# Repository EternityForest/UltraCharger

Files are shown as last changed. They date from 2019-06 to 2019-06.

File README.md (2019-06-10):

# UltraCharger
Highly experimental I2C solar battery charger frontend 

This little board is smaller than a buisiness card and basically acts as a frontend for ORing two inputs(2.1mm barrel),

putting the power through a buck-boost into a battery, measuring battery voltage and charge current, and providing 3.3v on the STEMMA
connector through a LDO regulator(Efficiency isn't an issue given the very low current needed to wake up one a second and do MPPT, and
occasionally report status).

There's no UI, it's meant for use with an ESP8266 breakout and UI via a remote machine.

This makes a ton of compromises to be smaller than a business card and on 2 layers. It's not tested and won't be till
I get the PCBs back. However it has been designed to be about as safe as any other consumer microcontroller-powered charger, when used
with the appropriate protection PCB for your battery.

The core is a 1A switching regulator set to 21V, for charging Ryobi One+ batteries. Even if the MCU fails it will not reach unsafe voltages.

That also should be witin the safe range of any decent 4S lithium protection PCB, unless they make thise crappier than I think,
so you should be able to charge 12V batteries and various LTO batteries.

You likely won't be getting more than 12-20 watts with this thing, and efficiency isn't fantastic, but it should be robust against all manner or transients and bad connections, aside from reverse battery which it handles with a clamp that trips the fuse or protection circuit you hopefully are using.

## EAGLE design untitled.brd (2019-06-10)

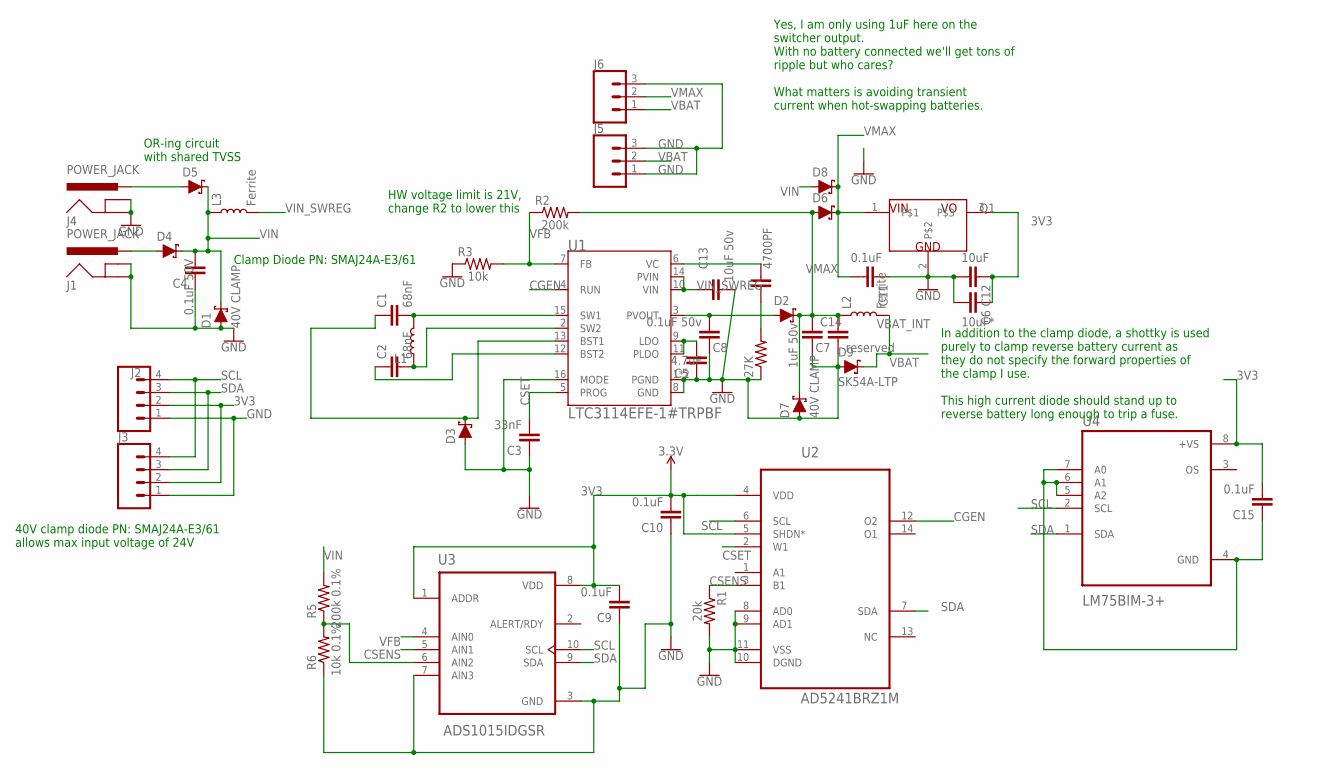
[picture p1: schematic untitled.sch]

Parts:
27K: 0805-EZ
4700PF: 1.0uF; 0805-EZ
C1, C2: 68nF; 0805-EZ
C3: 33nF; 0805-EZ
C4: 0.1uF 50V; 0805-EZ
C5: 4.7uF; 0805-EZ
C6: 10uF*; 0805-EZ
C7: reserved; 1206
C8: 0.1uF 50v; 0805-EZ
C9, C10, C11, C15: 0.1uF; 0805-EZ
C12: 10uF; 0805-EZ
C13: 10uF 50v; 1206
C14: 1uF 50v; 0805-EZ
D1, D7: 40V CLAMP; SMA-DIODE
D2, D3, D4, D5, D6, D8: 3A/40V/500mV; SMA-DIODE
D9: SK54A-LTP; SMA-DIODE
J1, J4: POWER_JACK; POWER_JACK_PTH
J2, J3: CONN_04JST-PTH-VERT; JST-4-PTH-VERT
J5, J6: CONN_03SCREW_LOCK; SCREWTERMINAL-3.5MM-3_LOCK.007S
L1: 27µH/±20%/3.3A; INDUCTOR_SDR1307
L2, L3: Ferrite; 0805
Q1: BD433M5FP-CE2TO252_STM; TO252_STM
R1: 20k; 0805-EZ
R2: 200k; 0805-EZ
R3: 10k; 0805-EZ
R5: 200k 0.1%; 0805-EZ
R6: 10k 0.1%; 0805-EZ
U1: LTC3114EFE-1#TRPBF; SOP65P640X110-17N
U2: AD5241BRZ1M; SOIC127P600X175-14N
U3: ADS1015IDGSR; SOP50P490X110-10N
U4: LM75BIM-3+; SOIC127P600X175-8N

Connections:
3V3: C6.1, C9.2, C10.2, C12.1, C15.2, J2.2, J3.2, Q1.3, U2.4 (VDD), U2.5 (SHDN*), U3.1 (ADDR), U3.8 (VDD), U4.8 (+VS)
CGEN: U1.4 (RUN), U2.12 (O2)
CSENS: R1.1, U2.3 (B1), U3.5 (AIN1)
CSET: C3.2, U1.5 (PROG), U2.2 (W1)
GND: 27K.1, C3.1, C4.1, C5.1, C6.2, C7.1, C8.1, C9.1, C10.1, C11.1, C12.2, C13.2, C14.2, D1.A, D3.A, D7.A, D9.A, J1.GND, J1.GNDBREAK, J2.1, J3.1, J4.GND, J4.GNDBREAK, J5.1, J5.3, J6.3, Q1.2, R1.2, R3.1, R6.1, U1.1 (PGND), U1.8 (GND), U1.16 (MODE), U1.17 (PGND), U2.8 (AD0), U2.9 (AD1), U2.10 (DGND), U2.11 (VSS), U3.3 (GND), U3.7 (AIN3)
unnamed: C1.2, L1.P$2 (2), U1.15 (SW1)
unnamed: C2.2, L1.P$1 (1), U1.2 (SW2)
unnamed: C1.1, D3.C, U1.13 (BST1)
unnamed: C2.1, U1.12 (BST2)
unnamed: D4.A, J1.PWR
unnamed: R5.1, R6.2, U3.6 (AIN2)
unnamed: C15.1, U4.4 (GND), U4.5 (A2), U4.6 (A1), U4.7 (A0)
unnamed: D5.A, J4.PWR
unnamed: C8.2, D2.A, U1.3 (PVOUT)
unnamed: C5.2, U1.9 (LDO), U1.11 (PLDO)
unnamed: 4700PF.2, U1.6 (VC)
unnamed: 27K.2, 4700PF.1
SCL: J2.4, J3.4, U2.6 (SCL), U3.10 (SCL), U4.2 (SCL)
SDA: J2.3, J3.3, U2.7 (SDA), U3.9 (SDA), U4.1 (SDA)
VBAT: D9.C, J5.2, J6.1, L2.2
VBAT_INT: C7.2, C14.1, D2.C, D6.A, D7.C, L2.1, R2.2
VFB: R2.1, R3.2, U1.7 (FB), U3.4 (AIN0)
VIN: C4.2, D1.C, D4.C, D5.C, D8.A, L3.1, R5.2
VIN_SWREG: C13.1, L3.2, U1.10 (VIN), U1.14 (PVIN)
VMAX: C11.2, D6.C, D8.C, J6.2, Q1.1

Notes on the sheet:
OR-ing circuit with shared TVSS
HW voltage limit is 21V, change R2 to lower this
40V clamp diode PN: SMAJ24A-E3/61 allows max input voltage of 24V
Yes, I am only using 1uF here on the switcher output. With no battery connected we'll get tons of ripple but who cares? What matters is avoiding transient current when hot-swapping batteries.
In addition to the clamp diode, a shottky is used purely to clamp reverse battery current as they do not specify the forward properties of the clamp I use. This high current diode should stand up to reverse battery long enough to trip a fuse.
Clamp Diode PN: SMAJ24A-E3/61

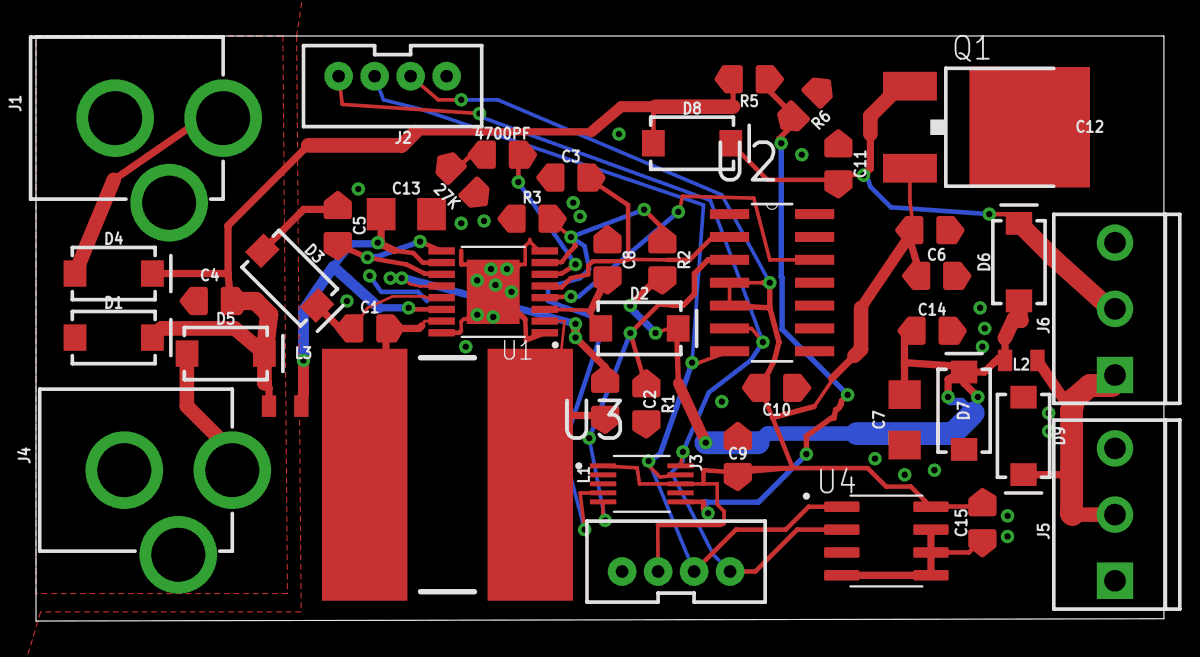
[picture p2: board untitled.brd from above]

Board: 2 copper layers, 62.7 x 32.5 mm, 45 parts (0 on the bottom side), 25 nets.

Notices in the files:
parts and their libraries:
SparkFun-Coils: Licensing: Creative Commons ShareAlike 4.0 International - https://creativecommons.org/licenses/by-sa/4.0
